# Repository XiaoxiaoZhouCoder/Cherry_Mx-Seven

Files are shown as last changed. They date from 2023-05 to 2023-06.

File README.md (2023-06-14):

---
Author  :Zhouty
Date    :2023.05.XX-2023.05.XX
Version :
---

**开始时间：** 2023.05 <br>
**结束时间：**  <br>
**项目说明：**  <br>
独立小键盘，7个独立按键，热插拔机械键轴，代码写入按键功能，同时也支持上位机改写各按键的功能。 <br>

```
|--项目文件夹目录
|--
|--01_Electric:         线路板设计文件
|--02_Code_Program:     嵌入式代码
|--03_Structural:       结构/壳体设计
|--04_Upper_Computer:   上位机设计
|--05_Document:         说明文档/参考文件等
|--06_Release:          项目发布文件
|--07_XXX.XX:           其它常用文件
|--
|--README.TXT:          项目说明文件
```

**项目说明：** <br>

> 有项目说明吗
> 没有

---
我已经做好修改了

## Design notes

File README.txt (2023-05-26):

XXXXXXXXXXXXXXXXXXXXXXXXXXXXXXXXXXXXXXXXXXXXXXXXXXXXXXXXXXXXXXXXXXXXXXXXXXXXXXXXXXX
 
XXXXXXXXXXXXXXXXXXXXXXXXXXXXXXXXXXXXXXXXXXXXXXXXXXXXXXXXXXXXXXXXXXXXXXXXXXXXXXXXXXX

开始时间：2023.05
结束时间：
项目说明：
独立小键盘，7个独立按键，热插拔机械键轴，代码写入按键功能，同时也支持上位机改写各按键的功能。

项目文件夹目录
|--01_Electric:		线路板设计文件
|--02_Code_Program:	嵌入式代码
|--03_Structural:	结构/壳体设计
|--04_Upper_Computer:	上位机设计
|--05_Document:		说明文档/参考文件等
|--06_Release:		项目发布文件
|--07_XXX.XX:		其它常用文件
|--
|--README.TXT:		项目说明文件

项目说明：

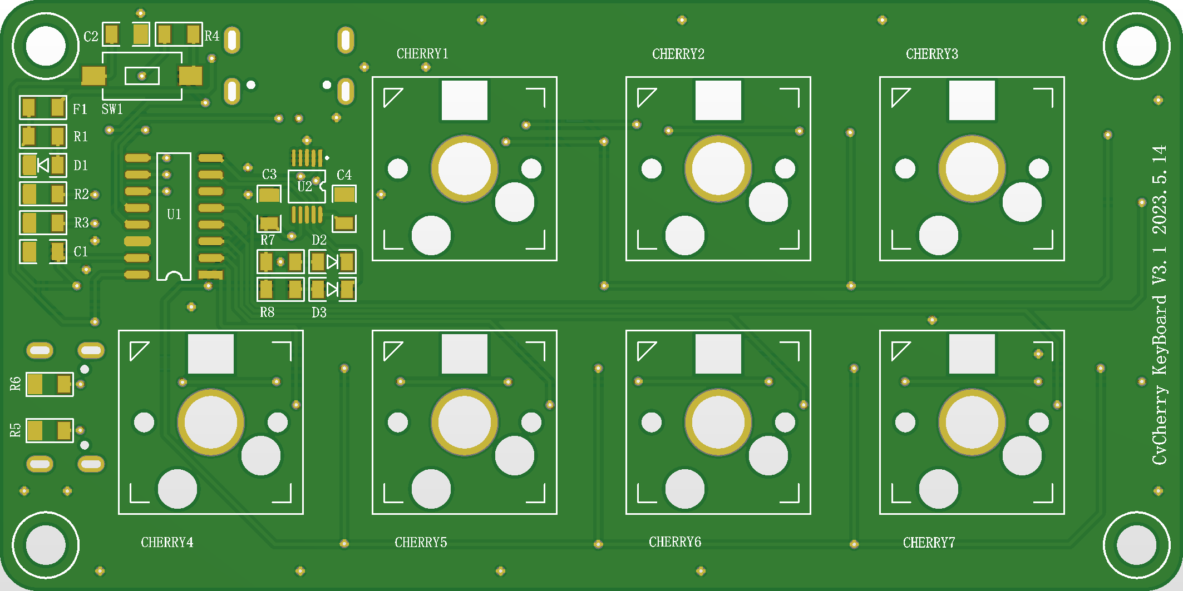
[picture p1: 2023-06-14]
03_Structural/02_Top_Cherry_Mx.png

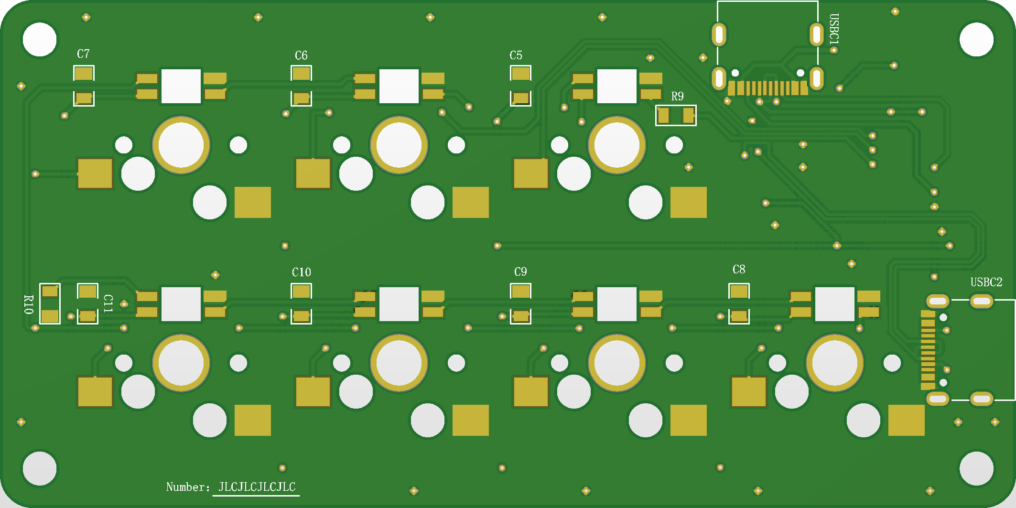
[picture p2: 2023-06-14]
03_Structural/02_Bottom_Cherry_Mx.png

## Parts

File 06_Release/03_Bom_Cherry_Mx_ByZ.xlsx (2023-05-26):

Description | Comment | Designator | Footprint | Quantity
贴片电阻 | 0Ω | R5, R6 | SM_R_0805 | 2
贴片电阻 | 4.7KΩ | R4 | SM_R_0805 | 1
贴片电阻 | 5.1KΩ | R2, R3 | SM_R_0805 | 2
贴片电阻 | 470Ω | R1, R7, R8 | SM_R_0805 | 3
贴片电阻 | 510Ω | R9, R10 | SM_R_0805 | 2
贴片电容 | 100nF | C1, C2, C3, C4, C5, C6, C7, C8, C9, C10, C11 | SM_C_0805 | 11
自恢复保险丝 | F_0805 | F1 | SMD_F_0805 | 1
直径3mm过孔 | M3 | MD1, MD2, MD3, MD4 | M3 | 4
沁恒串口转TTL | CH340E | U2 | MSOP-10 | 1
沁恒USB芯片 | CH549G | U1 | SOP-16 | 1
樱花轴CHERRY | Cherry_RGB | CHERRY1, CHERRY2, CHERRY3, CHERRY4, CHERRY5, CHERRY6, CHERRY7 | Cherry | 7
按钮轻触开关 | 轻触开关 | SW1 | SW_L6W3.5 | 1
发光二极管 | LED_0805 | D1, D2, D3 | LED_0805_White | 3
USB连接器 | TYPE-C_16PIN | USBC1, USBC2 | SMD_TYPE-C_16PIN_WS | 2

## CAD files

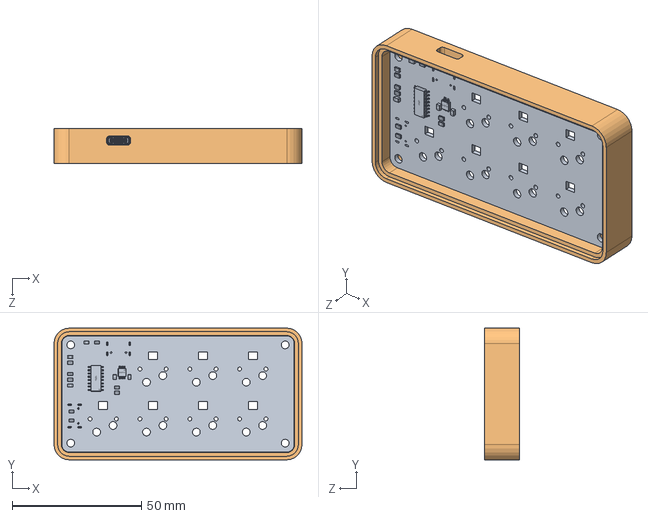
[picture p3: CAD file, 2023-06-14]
03_Structural/03_Asm_Cherry_Mx.SLDASM
96.0 x 51.0 x 13.5 mm
02_Board_Cherry_Mx_ByZ
04_Shell_Cherry_Mx

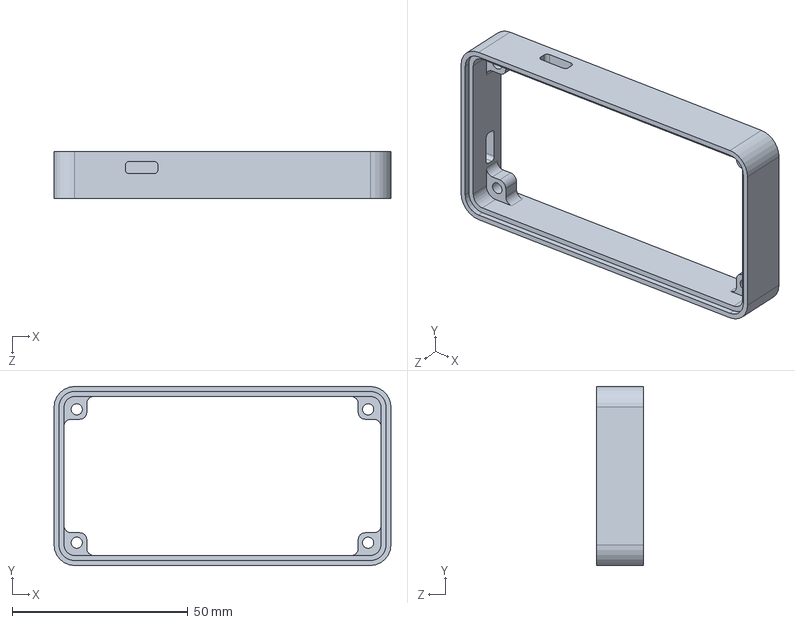
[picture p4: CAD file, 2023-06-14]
03_Structural/04_Shell_Cherry_Mx.sldprt
96.0 x 51.0 x 13.5 mm

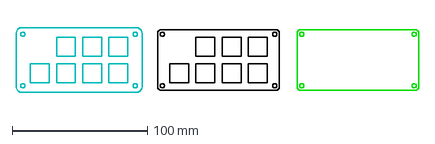
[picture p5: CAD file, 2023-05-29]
03_Structural/01_Panel_Top_CvCherry.DXF
297.5 x 48.0 mm

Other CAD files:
06_Release/05_Shell_Cherry_Mx.STL

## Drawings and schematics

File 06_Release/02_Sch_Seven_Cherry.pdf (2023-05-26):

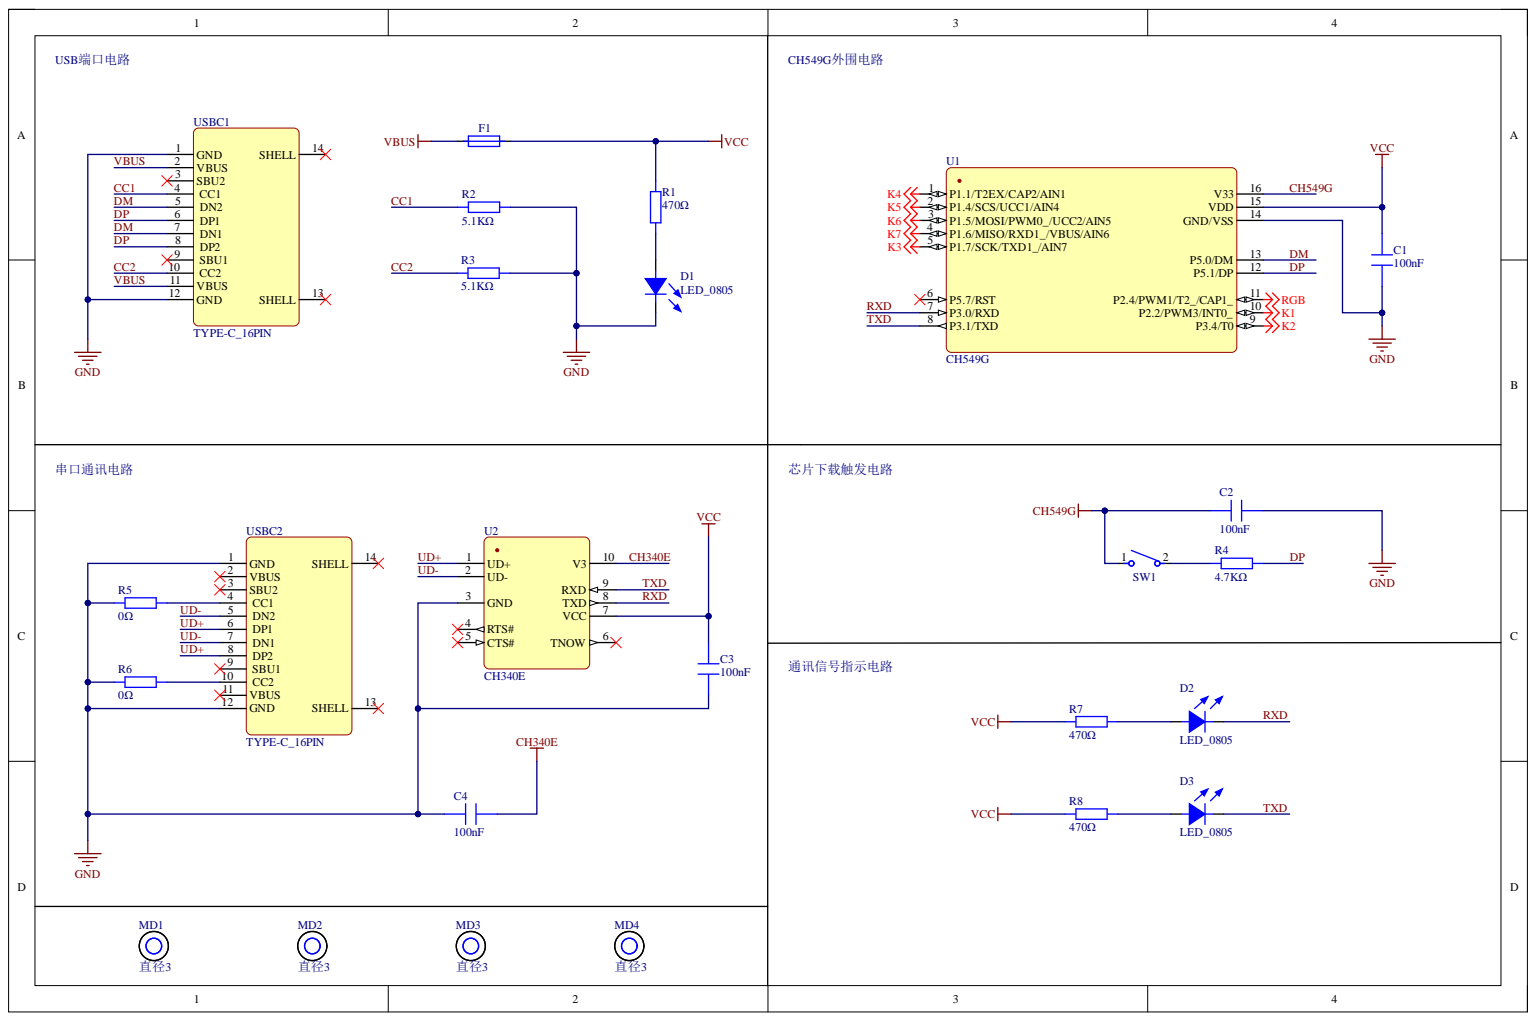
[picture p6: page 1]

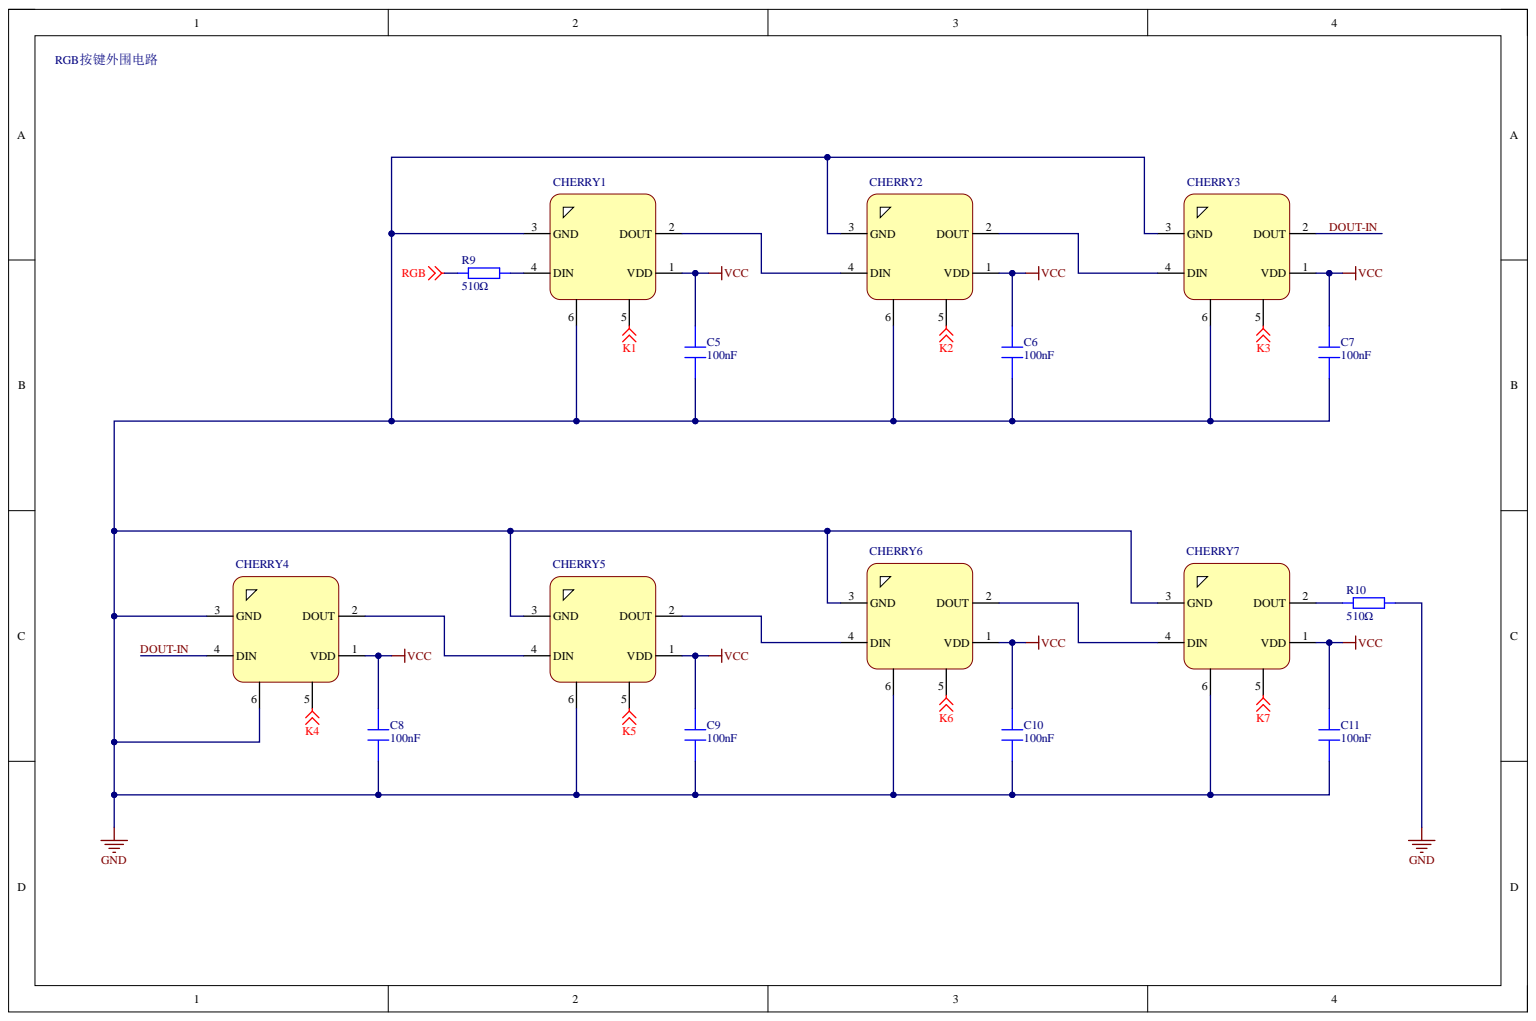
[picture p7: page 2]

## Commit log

2023-05-18 提交PCB工程文件，V2.2。
    [Cherry_Mx_ByZ.PrjPcb, Cherry_Mx_ByZ.SchDoc, Switch_RGB_Cherry.SchDoc]
2023-05-20 提交PCB修改文件,V2.3。 更新说明：1、修改两个type-c口的位置
    [Cherry_Mx_ByZ.SchDoc, Switch_RGB_Cherry.SchDoc]
2023-05-21 *版本更新，V2.4。 1、去除MARK点。 2、添加可视化BOM文件。
    [Cherry_Mx_ByZ.SchDoc]
2023-05-26 更新项目文件 1.添加可发布的原理图PDF，BOM，Gerber文件； 2.更新部分库器件封装名称，R，IC，SW； 3.更新InteractiveBOM.HTML文件（可交互式BOM）；
    [03_Bom_Cherry_Mx_ByZ.xlsx, Cherry_Mx_ByZ.PrjPcb, Cherry_Mx_ByZ.SchDoc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]
2023-05-26 Update README.txt
    修改README文件项目说明内容。
2023-05-26 更新README为Markdown格式
2023-05-29 修改README.md文件开头
2023-05-29 Update README.md
    修改README浏览器预览效果
2023-05-29 更新README标题
2023-05-29 添加线路板和面板的板框CAD文件 1.添加线路板和面板的板框CAD文件； 2.更新README内容缩进；
    [01_Panel_Top_CvCherry.DXF]
2023-05-29 修改README文件内容缩进
2023-06-14 修改丝印，更新版本为V3.1 1.修改版本号丝印 2.修改客户编号丝印 3.修改USB2丝印方向 4.修改3D模型线路板的板厚 5.添加结构相关文件
    [03_Asm_Cherry_Mx.SLDASM, 04_Shell_Cherry_Mx.sldprt, 05_Shell_Cherry_Mx.STL]
